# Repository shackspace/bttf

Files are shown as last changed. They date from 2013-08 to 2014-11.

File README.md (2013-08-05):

BTTF Clock
==========

A triple wall clock modeled after the Time Circuits from a well-known SF movie of the 80s.

Designed by [Timm][1] and [Jocki][2] of [shackspace][3], together with and for our friends at [PCB-Pool][4].

Technology
==========

The clock is driven by an Arduino or a compatible uC board. It consists of two components:

 1. A shield for the Arduino which houses a battery-backed real-time clock (RTC) and combines Arduino pins and power into a bus.
 1. A display board representing a single clock, including numeric and alphanumeric LED displays, LEDs, LED drivers and brightness control.
    The display boards can be daisy-chained to an almost arbitrary amount. For a full triple clock, you'd use three of these, with differently colored LEDs.

Display Bus
-----------

The display bus consists of ground, two power rails and five logic signals. The two power rails are logic power and LED power -- both run at 5V, but the shield allows to separate them and power the LEDs from an external power supply while the logic including the Arduino is powered through USB. This is to prevent the external power supply from feeding into the USB or vice versa. Powering the whole clock from a PC USB port is usually not possible because the LEDs draw up to one Ampere and most hosts will disable the port as soon as the displays turn on.

The logic pins are what's needed to control a multiplexed display driven by a TLC59282 constant-current shift register towards ground, and a 74HC164 non-latching shift register power p-FETs towards 5V:

 * The TLC is controlled by the LATCH and BLANK signals, data is shifted in using the SDATA\_IN and SCLK signals. The SDATA\_OUT signal of one display connects to SDATA\_IN of the next display in the chain.
 * The shift register is clocked whenever the TLC is latched, so the LATCH signal can serve as its clock. In addition, we need a serial input !COL0 that is set to 0 (turning the p-FET on) on the first multiplex step and 1 (turning the p-FET off) on all other steps, so that we have a single "p-FET on" signal clocking through the shift register.

All signals but the SDATA_IN/OUT signals are connected in parallel across all display modules, the SDATA signals are daisy-chained from one module to the next -- as a result of this, each module has a distinct input and output connector.

Subdirectories
==============

[controller](controller) - The Arduino shield, designed in [Eagle][5], complete with BOM in CSV format.  
[display](display) - The display module, designed using [KiCad][6] because it exceeds Eagle's size limits, also with BOM.  
[firmware](firmware) - The full firmware, ready for upload using the Arduino IDE.

Setting up
==========

To complete the clock into a working thing (after soldering), you will need a battery, an Arduino (or compatible) and a 5V 1A power supply with the usual barrel plug (center positive). Put the battery into the holder, put the shield on the Arduino, connect it to the first display using a ribbon cable. The top connector on each display is the input, the bottom one is the output. Daisy-chain as many displays as you like - or have ;)

The power supply goes into the shield, not the Arduino. There's a jumper on the shield that connects the LED driver's power supply (fed through the barrel jack) and the logic power supply (including the Arduino) – leave that open if you have both the Arduino connected to the PC and the power supply hooked up to the shield, otherwise close it.

Upload the firmware to the Arduino and connect to it using the Serial Monitor at 9600 Baud. Send a "?" to the Arduino to get some help on how to set up the clock. Each display line can be set to display either a fixed value (any alphanumerical+numerical string, not just a valid time) or the current time as delivered by the battery-backed RTC. To make the RTC start ticking, you will have to set its time once. You can set each display's brightness using the trimmers on the back – you might even be able to power the thing via USB on lowest brightness, but no guarantees.

[1]: http://twitter.com/timmedia
[2]: http://twitter.com/dop3j0e
[3]: http://shackspace.de/
[4]: http://pcb-pool.com/
[5]: http://www.cadsoft.de/eagle-pcb-design-software/
[6]: http://www.kicad-pcb.org/

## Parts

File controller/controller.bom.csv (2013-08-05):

Part | Value | Device | Package | Description | Description2 | Qty | Place_YES/NO | Povided_by_customer_YES/NO | Distributor | Ordernumber | Weblink | Remarks_customer | Unit_price | Total_price | REMARKS_BETA | OPTION1 | OPTION2 | OPTION3
BAT | CR2032 | CR2032 | HAR-S8421 | CR2032 Battery Holder |  | 1 | yes | no | Digikey | 952-1737-1-ND | http://www.digikey.de/scripts/DKSearch/dksus.dll?Detail&itemSeq=119976446&uq=634847035775684144
C1, C2 | 22p | C-EUC0603 | C0603 | CAPACITOR, European symbol |  | 2 | no | no
C3 | 100n | C-EUC0603K | C0603K | CAPACITOR, European symbol |  | 1 | yes | no | Beta | 6242480 | http://de.rs-online.com/web/search/searchBrowseAction.html?method=searchProducts&searchTerm=6242480
C4 | 100p | C-EUC0603 | C0603 | CAPACITOR, European symbol |  | 1 | no | no
C5 | 10u | CPOL-EUC/6032-28R | C/6032-28R | POLARIZED CAPACITOR, European symbol | Tantalkondensator, 6032-28, 25V, 10µF | 1 | yes | no | Beta | 4649306P | http://uk.rs-online.com/web/search/searchBrowseAction.html?method=searchProducts&searchTerm=4649306P&x=0&y=0
JP1 |  | JP1E | JP1 | JUMPER |  | 1 | no | no
PWR | 2.1MMJACKTHM | 2.1MMJACKTHM | PJ-102A | 2.1mm x 5.5mm THM DC jack with internal switch |  | 1 | yes | no | Digikey | CP-202A-ND | http://www.digikey.de/scripts/DKSearch/dksus.dll?Detail&itemSeq=119976434&uq=634847035775684144
Q1 | 32.768kHz | CRYSTALMM20SS | MM20SS | CRYSTAL |  | 1 | yes | no | Digikey | 631-1000-1-ND | http://www.digikey.de/scripts/DKSearch/dksus.dll?Detail&itemSeq=119976445&uq=634847035775684144
R1 | 1k | R-EU_R0603 | R0603 | RESISTOR, European symbol | RESISTOR, 0.1W, 1% | 1 | yes | no | Beta | 6979246 | http://uk.rs-online.com/web/search/searchBrowseAction.html?method=getProduct&R=6979246
R2, R3 | 2k2 | R-EU_R0603 | R0603 | RESISTOR, European symbol | RESISTOR, 0.1W, 1% | 2 | yes | no | Beta | 6979270 | http://uk.rs-online.com/web/search/searchBrowseAction.html?method=getProduct&R=6979270
R4 | 10k | R-EU_R0603 | R0603 | RESISTOR, European symbol | RESISTOR, 0.1W, 1% | 1 | yes | no | Beta | 6979325 | http://uk.rs-online.com/web/search/searchBrowseAction.html?method=getProduct&R=6979325
R5, R6, R7, R8 | 0R | R-EU_R0603 | R0603 | RESISTOR, European symbol |  | 4 | no | no
RTC | MCP7940N | MCP7940N | SO08 | Microchip MCP7940N RTC |  | 1 | yes | no | Digikey | MCP7940N-I/SN-ND | http://www.digikey.de/scripts/DKSearch/dksus.dll?Detail&itemSeq=119976456&uq=634847035775684144
X1 |  | 2516- | PAK100/2500-16 | 2x8 Wannensteckverbinder |  | 1 | yes | no | Digikey | S9171-ND | http://www.digikey.de/scripts/DKSearch/dksus.dll?Detail&itemSeq=119976334&uq=634847035775684144
NOT ON BOARD | 5V 2A |  |  | DC Power Supply |  | 1 | no |  | Digikey | T1150-P5P-ND | http://www.digikey.de/scripts/DKSearch/dksus.dll?Detail&itemSeq=119976439&uq=634847035775684144

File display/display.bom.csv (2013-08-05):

Ref | Value | Beschreibung | Qty | Place_YES/NO | Distributor | Teilenummer
BESTÜCKUNG FÜR ROTES DISPLAY:
AFF4..AFF13 |  | 7 Segment Rot SA08-11EWA | 10 (ROT) | yes | Distrelec | 661208
AFF1..AFF3 |  | 16 Segment Rot PSA08-11EWA | 3 (ROT) | yes | Distrelec | 661280
D1...D4 |  | LED 3MM RED 6.3MCD GAASP ON GAP Rot | 4 (ROT) | yes | Digikey | 751-1129-ND
BESTÜCKUNG FÜR GRÜNES DISPLAY:
AFF4..AFF13 |  | 7 Segment Grün SA08-11GWA | 10 (GRÜN) | yes | Distrelec | 661210
AFF1..AFF3 |  | 16 Segment Grün PSA08-11GWA | 3 (GRÜN) | yes | Distrelec | 661282
D1...D4 |  | LED 3MM GREEN 6.3MCD GAP ON GAP Grün | 4 (GRÜN) | yes | Digikey | 751-1101-ND
BESTÜCKUNG FÜR GELBES DISPLAY:
AFF4..AFF13 |  | 7 Segment Gelb SA08-11YWA | 10 (GELB) | yes | Distrelec | 661212
AFF1..AFF3 |  | 16 Segment Gelb PSA08-11YWA | 3 (GELB) | yes | Distrelec | 661284
D1...D4 |  | LED 3MM YLW 6.3MCD GAASP ON GAP Gelb | 4 (GELB) | yes | Digikey | 751-1144-ND
GEMEINSAME BESTÜCKUNG FÜR ALLE DISPLAYS:
U1 |  | TI TLC59282DBQR | 1 | yes | Digikey | 296-28098-1-ND
P1, P2 |  | CONN HEADER 2.54MM 16POS GOLD | 2 | yes | Digikey | S9171-ND
U2 |  | SN74HC164DR IC SHIFT REGISTER 8BIT 14-SOIC | 1 | yes | Digikey | 296-14838-1-ND
Q1...Q8 |  | IRLML6401PBFCT-ND P-MOS FET | 8 | yes | Digikey | IRLML6401PBFDKR-ND
R1 | 1K2 1% | RES 1.20K OHM 1/10W 1% 0603 SMD | 1 | yes | Digikey | 311-1.20KHRCT-ND
R2, R3, R4, R5 |  | Platzhalter für evtl. notwendige Termination, nicht bestücken! | 4 | no
RV1 | 5K 20% | TRIMMER 5K OHM 0.25W SMD | 1 | yes | Digikey | ST4ETA502CT-ND
C1, C2 | 47uF | Tantalkondensator, 6032-28, 16V, 47µF | 2 | yes | Beta | 4648016P
C3, C4 | 100n | CAP CER 0.1UF 16V 10% X7R 0603 | 2 | yes | Digikey | 478-1239-1-ND

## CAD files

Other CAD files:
frontpanel/BttF_Uhr_Front.DXF

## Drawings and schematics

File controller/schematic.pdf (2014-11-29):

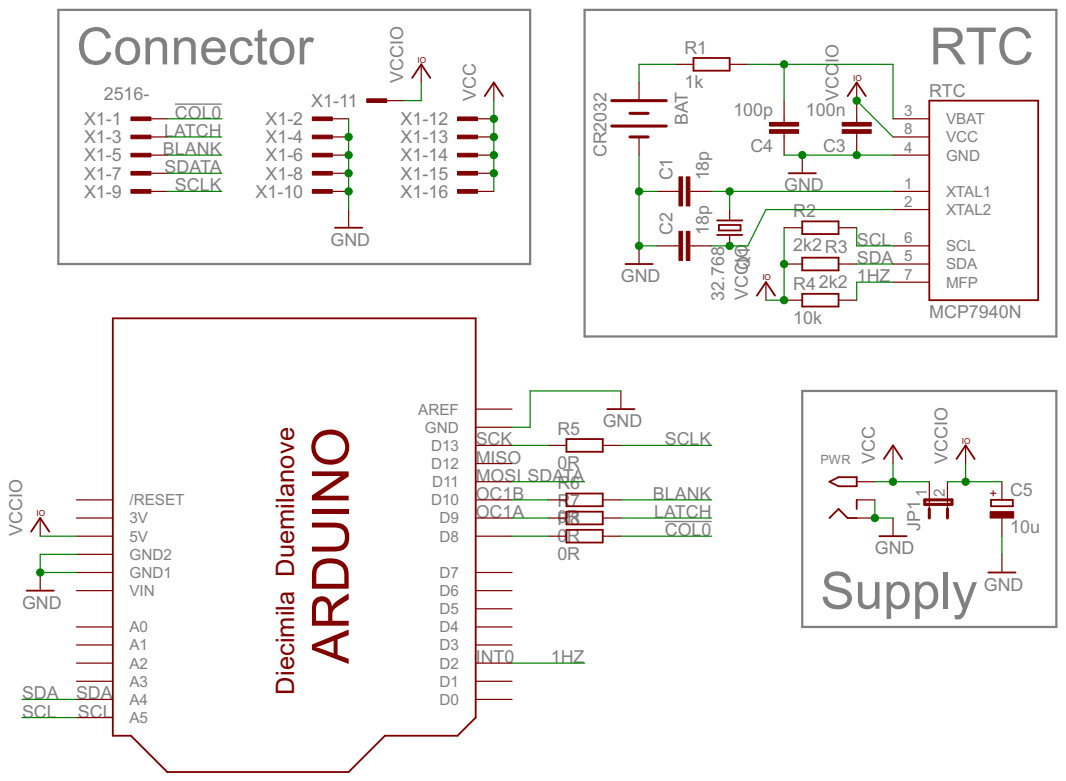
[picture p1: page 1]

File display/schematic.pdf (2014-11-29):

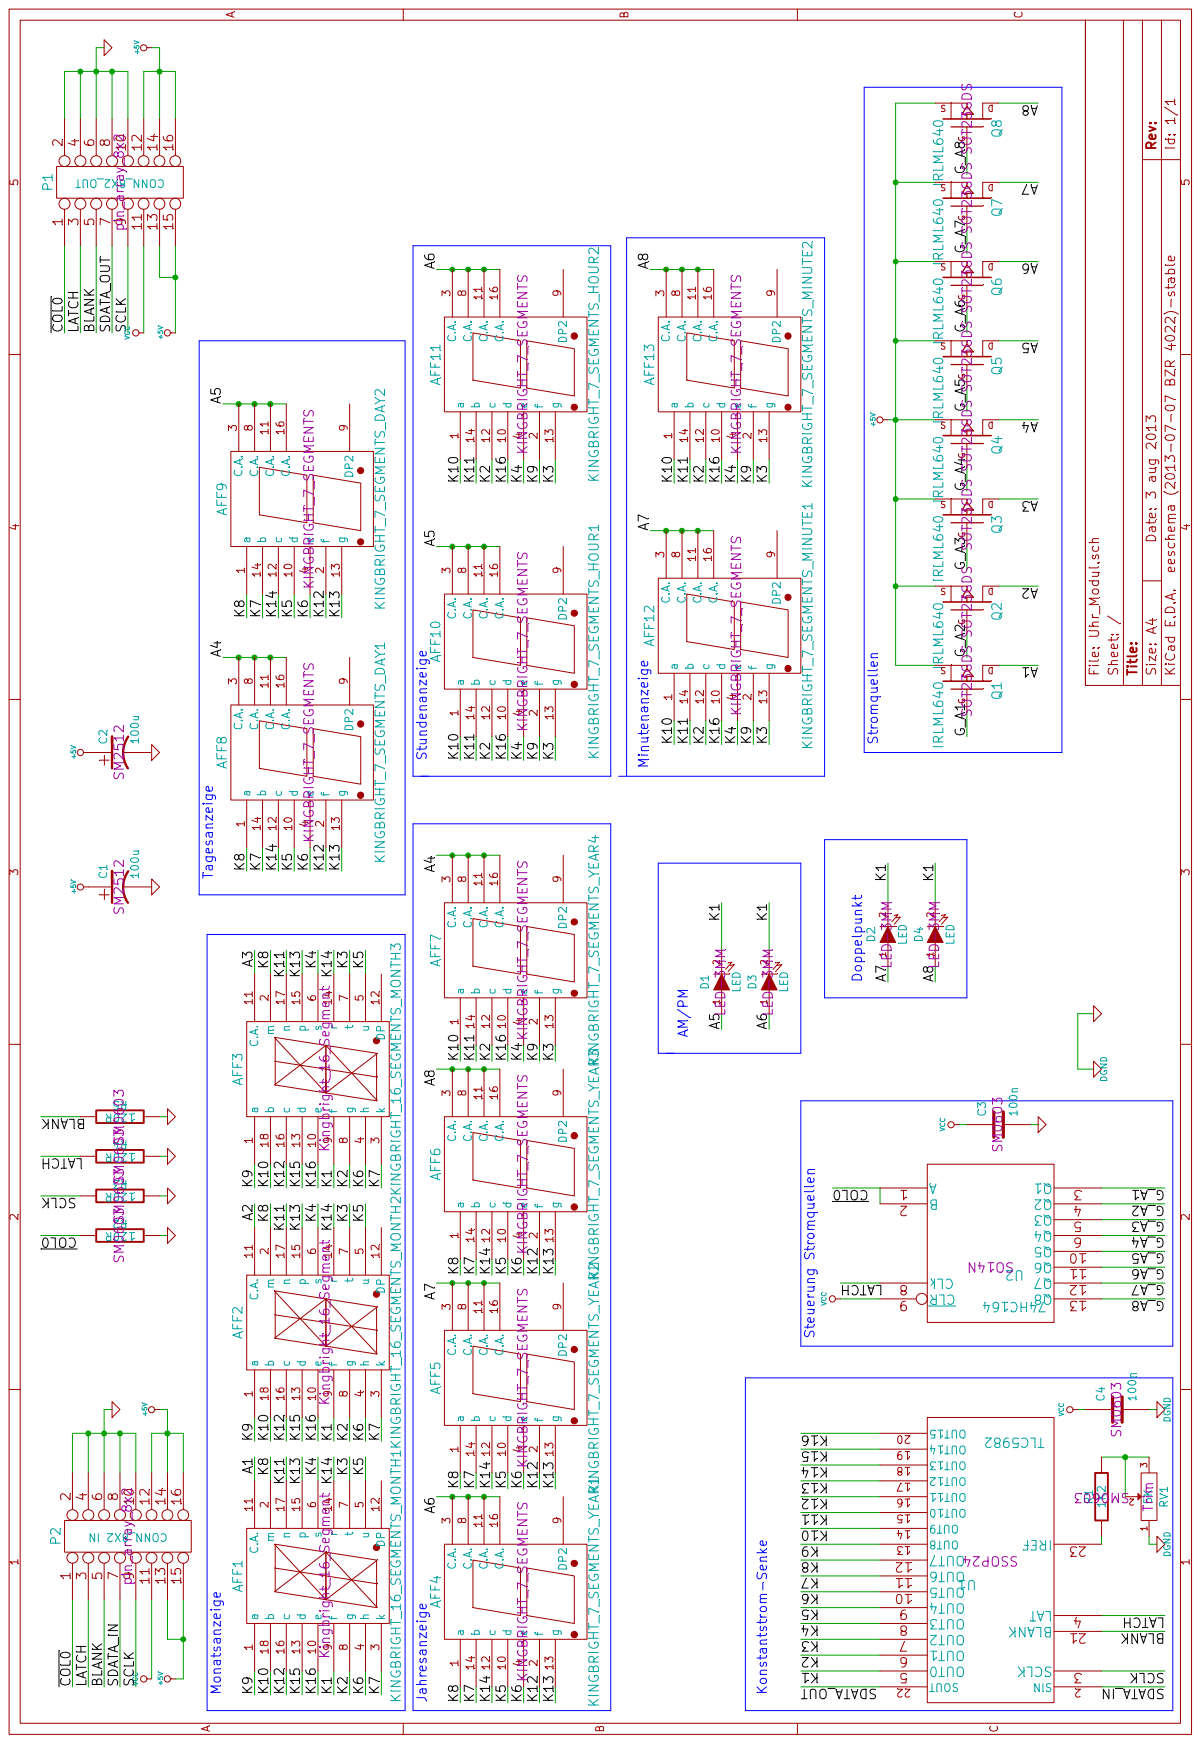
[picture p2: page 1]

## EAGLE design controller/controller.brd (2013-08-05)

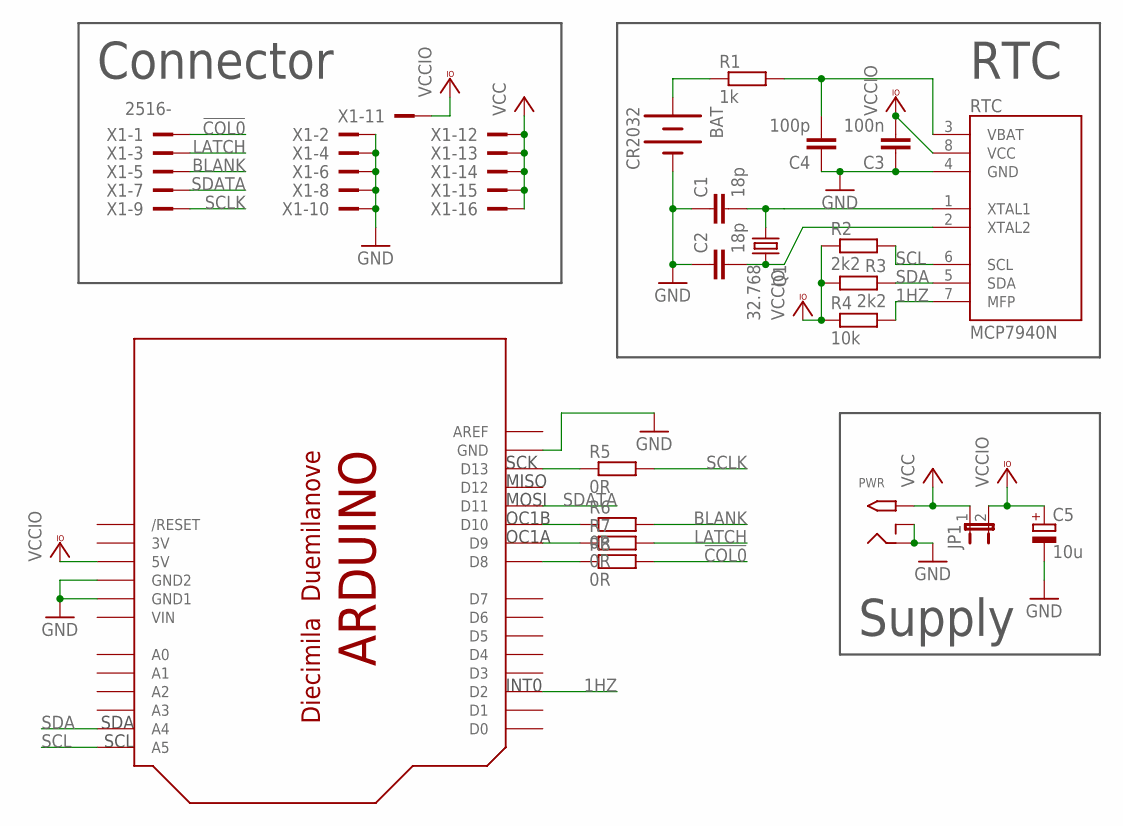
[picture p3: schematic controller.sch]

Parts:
ARDU: ARDUINODUEMILANOVE; ARDUINO
BAT: CR2032; HAR-S8421
C1, C2: 18p; C0603
C3: 100n; C0603K
C4: 100p; C0603
C5: 10u; C/6032-28R
JP1: JP1E; JP1
PWR: 2.1MMJACKTHM; PJ-102A
Q1: 32.768; MM20SS
R1: 1k; R0603
R2, R3: 2k2; R0603
R4: 10k; R0603
R5, R6, R7, R8: 0R; R0603
RTC: MCP7940N; SO08
X1: 2516-; PAK100/2500-16

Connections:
1HZ: ARDU.D2, R4.2, RTC.7 (MFP)
3V: ARDU.3V
!COL0: R8.2, X1.1
BLANK: R6.2, X1.5
GND: ARDU.GND, ARDU.GND1, ARDU.GND2, BAT.-, C1.1, C2.1, C3.1, C4.1, C5.-, PWR.RING, PWR.RING_SW, RTC.4 (GND), X1.2, X1.4, X1.6, X1.8, X1.10
LATCH: R7.2, X1.3
unnamed: C1.2, Q1.1, RTC.1 (XTAL1)
unnamed: C2.2, Q1.4 (2), RTC.2 (XTAL2)
unnamed: BAT.+, R1.1
unnamed: C4.2, R1.2, RTC.3 (VBAT)
unnamed: ARDU.D13, R5.1
unnamed: ARDU.D10, R6.1
unnamed: ARDU.D9, R7.1
unnamed: ARDU.D8, R8.1
SCL: ARDU.A5, R2.2, RTC.6 (SCL)
SCLK: R5.2, X1.9
SDA: ARDU.A4, R3.1, RTC.5 (SDA)
SDATA: ARDU.D11, X1.7
VCC: JP1.1, PWR.TIP, X1.12, X1.13, X1.14, X1.15, X1.16
VCCIO: ARDU.5V, C3.2, C5.+, JP1.2, R2.1, R3.2, R4.1, RTC.8 (VCC), X1.11
VIN: ARDU.VIN

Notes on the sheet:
Connector
RTC
Supply
SCK
MISO
MOSI
OC1B
OC1A
INT0
SDA
SCL

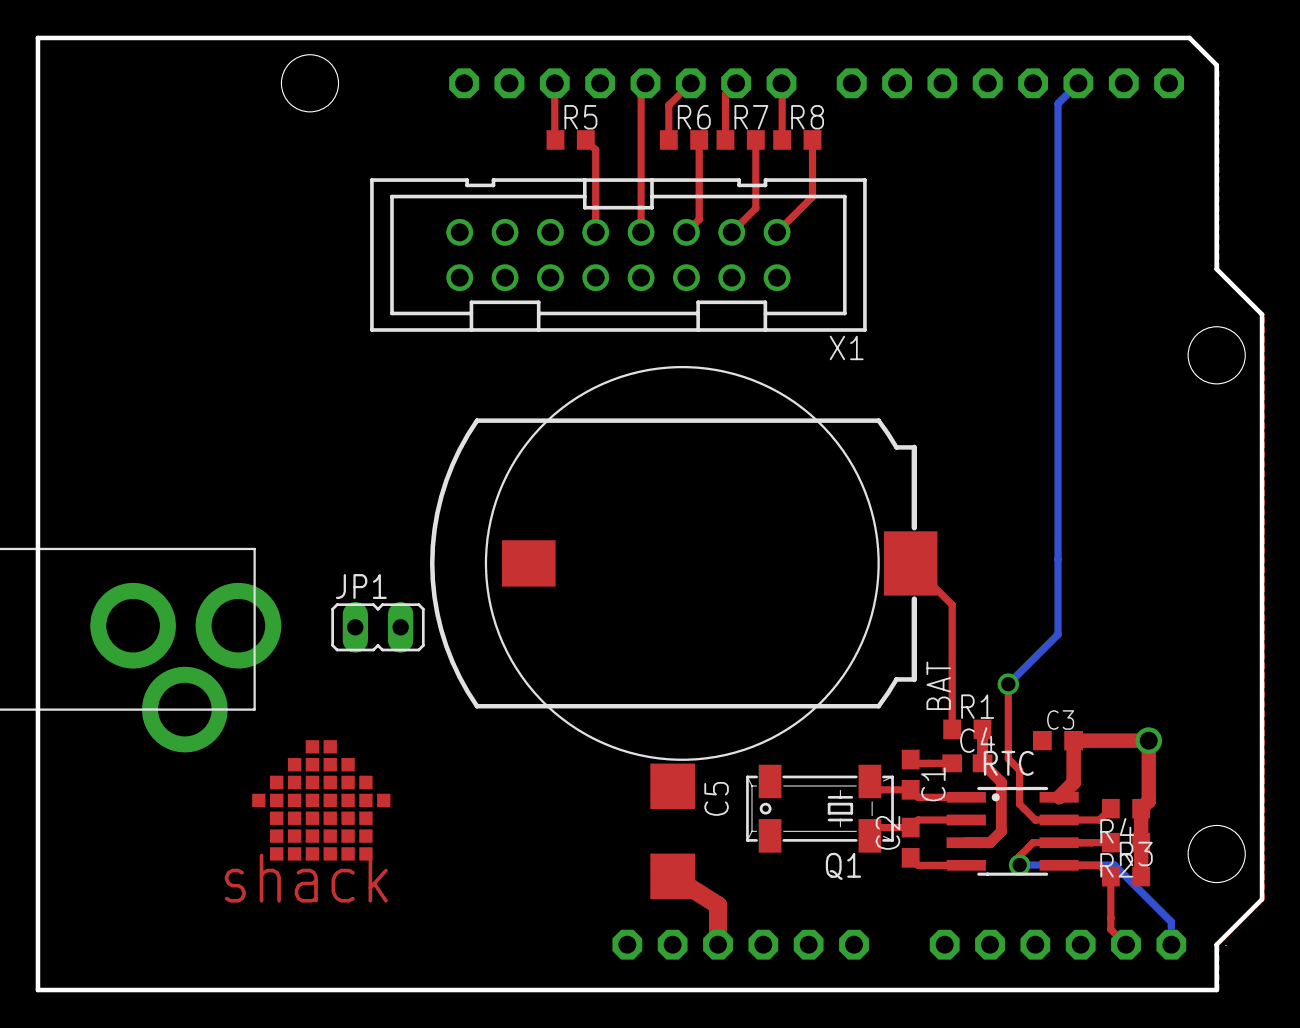
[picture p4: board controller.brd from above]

Board: 2 copper layers, 68.6 x 53.3 mm, 20 parts (0 on the bottom side), 19 nets.

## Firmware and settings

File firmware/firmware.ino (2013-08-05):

#include <stdio.h>
#include <stdlib.h>
#include <stdint.h>

#include <Wire.h>
#include <SPI.h>
#include <EEPROM.h>

#include "firmware.h"

void saveConfig()
{
	for (uint8_t i = 0; i < sizeof(displays); i++)
	{
		EEPROM.write(i, ((uint8_t *)displays)[i]);
	}
}

static void loadConfig()
{
	for (uint8_t i = 0; i < sizeof(displays); i++)
	{
		((uint8_t *)displays)[i] = EEPROM.read(i);
	}
}

void setup()
{
	loadConfig();
	setupRtc();
	setupDisplayDriver();
	Serial.begin(9600);
}

void loop()
{
	checkCommand();
}

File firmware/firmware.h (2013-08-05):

#ifndef FIRMWARE_H
#define FIRMWARE_H

#include <stdio.h>
#include <stdlib.h>
#include <stdint.h>
#include <avr/pgmspace.h>

#define NUM_DISPLAYS 3

#define LED_AM (1 << 4)
#define LED_PM (1 << 5)
#define LED_SEC1 (1 << 6)
#define LED_SEC2 (1 << 7)
#define LED_CATHODE (1 << 0)

#define bcd2dec(x) (((((x) >> 4) & 0xF) * 10) + ((x) & 0xF))

#define COL0_PIN 8
#define SECONDS_PIN 2

/* Don't change these, they correspond to OC1A and OC1B */
#define LATCH_PIN 9
#define BLANK_PIN 10

/* offsets in the digits array */
#define DAY 0
#define YEAR 2
#define HOUR 6
#define MINUTE 8

/* from main file */

void saveConfig();

/* from fonts.c */

extern const PROGMEM uint16_t font16['Z' - '0' + 1];
extern const PROGMEM uint16_t font7a[10];
extern const PROGMEM uint16_t font7b[10];

/* from rtc.cpp */

#define RTC_I2C_ADDRESS 0x6F

struct Time {
	uint8_t seconds, minutes, hours, day, month, year;
	bool pm;
};

extern Time rtc;

void setupRtc();
void loadRtcTime();
void setRtcTime(Time &time);

/* from display.cpp */

struct Display {
	bool useRtc;
	char month[3];
	uint8_t digits[10];
	uint8_t leds;
};

extern Display displays[NUM_DISPLAYS];

void setupDisplayDriver();
void setDisplay(Display *disp, Time &time);

/* from serial.cpp */

void checkCommand();

#endif

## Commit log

2014-11-29 Add schematic PDFs
2015-01-23 added frontpanel image sources
    [BttF_Uhr_Front.DXF]
